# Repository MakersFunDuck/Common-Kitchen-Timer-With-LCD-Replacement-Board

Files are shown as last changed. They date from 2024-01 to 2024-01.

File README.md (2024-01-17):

# Common Kitchen Timer With an LCD-Replacement Board
A replacement PCB board for common 4 digit 7 segment LCD kitchen timers

It uses a cheap TM1621D LCD driver. You can solder either Attiny13A, or ESP12E module. 

The "Print" function can print out supported letters on the screen. However it is not optimised for memory constains for Attiny13A.

<p align="center">
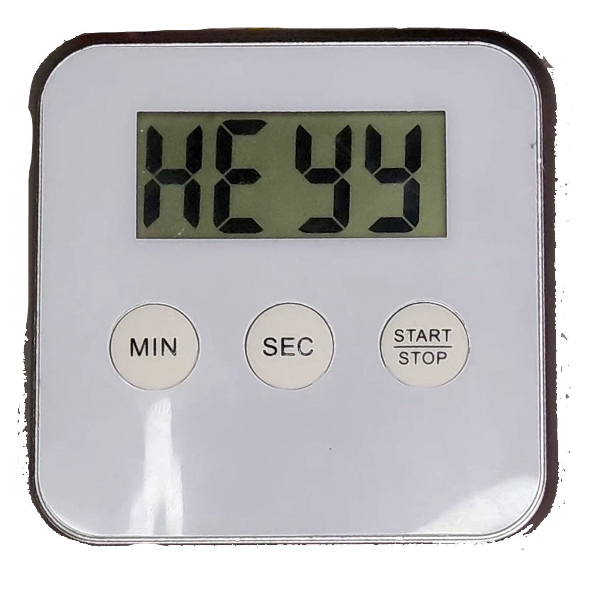
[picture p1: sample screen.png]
Sample Screen
  

</p>

**Folder descriptions:**

**Datasheets:** Where datasheets of the components are located (also translations from Chinese)

**Fabrication files:** Gerber files. You can just upload those to any PCB manufacturer website to get your PCB.

**Firmware:** Code examples which is written using Arduino framework.

**KiCAD files:** KiCAD schematics and PCB files

**Schematics and Layout files:** PDF files for the PCB and Schematics.

If you want to use another LCD, or make your own PCB designs, I explained them in a video if you are interested. 
https://youtu.be/JNZbfLtlbZA

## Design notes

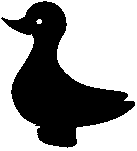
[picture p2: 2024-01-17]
KiCAD files/duck symb.bmp

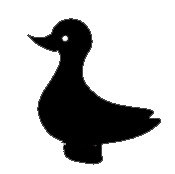
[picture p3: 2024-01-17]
KiCAD files/Screenshot 2023-12-29 142127.png

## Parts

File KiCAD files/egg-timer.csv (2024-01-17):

# | Reference | Qty | Value | Footprint | DNP
1 | BZ1 | 1 | Buzzer | Buzzer_Beeper:Buzzer_12x9.5RM7.6
2 | C1, C3 | 2 | 10uF | Capacitor_SMD:C_0805_2012Metric_Pad1.18x1.45mm_HandSolder
3 | C2, C4 | 2 | 100nF | Capacitor_SMD:C_0805_2012Metric_Pad1.18x1.45mm_HandSolder
4 | J1 | 1 | Conn_01x05 | Connector_PinHeader_2.00mm:PinHeader_1x05_P2.00mm_Vertical
5 | J2, J3, J4, J5 | 4 | Conn_01x01 | Connector_PinHeader_2.00mm:PinHeader_1x01_P2.00mm_Vertical
6 | R1, R2, R4 | 3 | 1k | Resistor_SMD:R_0805_2012Metric_Pad1.20x1.40mm_HandSolder
7 | R3 | 1 | 1K | Resistor_SMD:R_0805_2012Metric_Pad1.20x1.40mm_HandSolder
8 | R5 | 1 | 0Ω | Resistor_SMD:R_0805_2012Metric_Pad1.20x1.40mm_HandSolder
9 | RV1 | 1 | Varistor | Potentiometer_THT:Potentiometer_Runtron_RM-065_Vertical
10 | SW1, SW2, SW3 | 3 | SW_Push | lcd:contact pad
11 | U1 | 1 | ESP-12E | RF_Module:ESP-12E
12 | U2 | 1 | TM1621D | Package_SO:SOIC-24W_7.5x15.4mm_P1.27mm
13 | U3 | 1 | bare-lcd | lcd:bare-lcd-footprint12
14 | U4 | 1 | AMS1117-3.3 | Package_TO_SOT_SMD:SOT-223-3_TabPin2
15 | U5 | 1 | ATtiny13A-S | Package_SO:SOIC-8W_5.3x5.3mm_P1.27mm

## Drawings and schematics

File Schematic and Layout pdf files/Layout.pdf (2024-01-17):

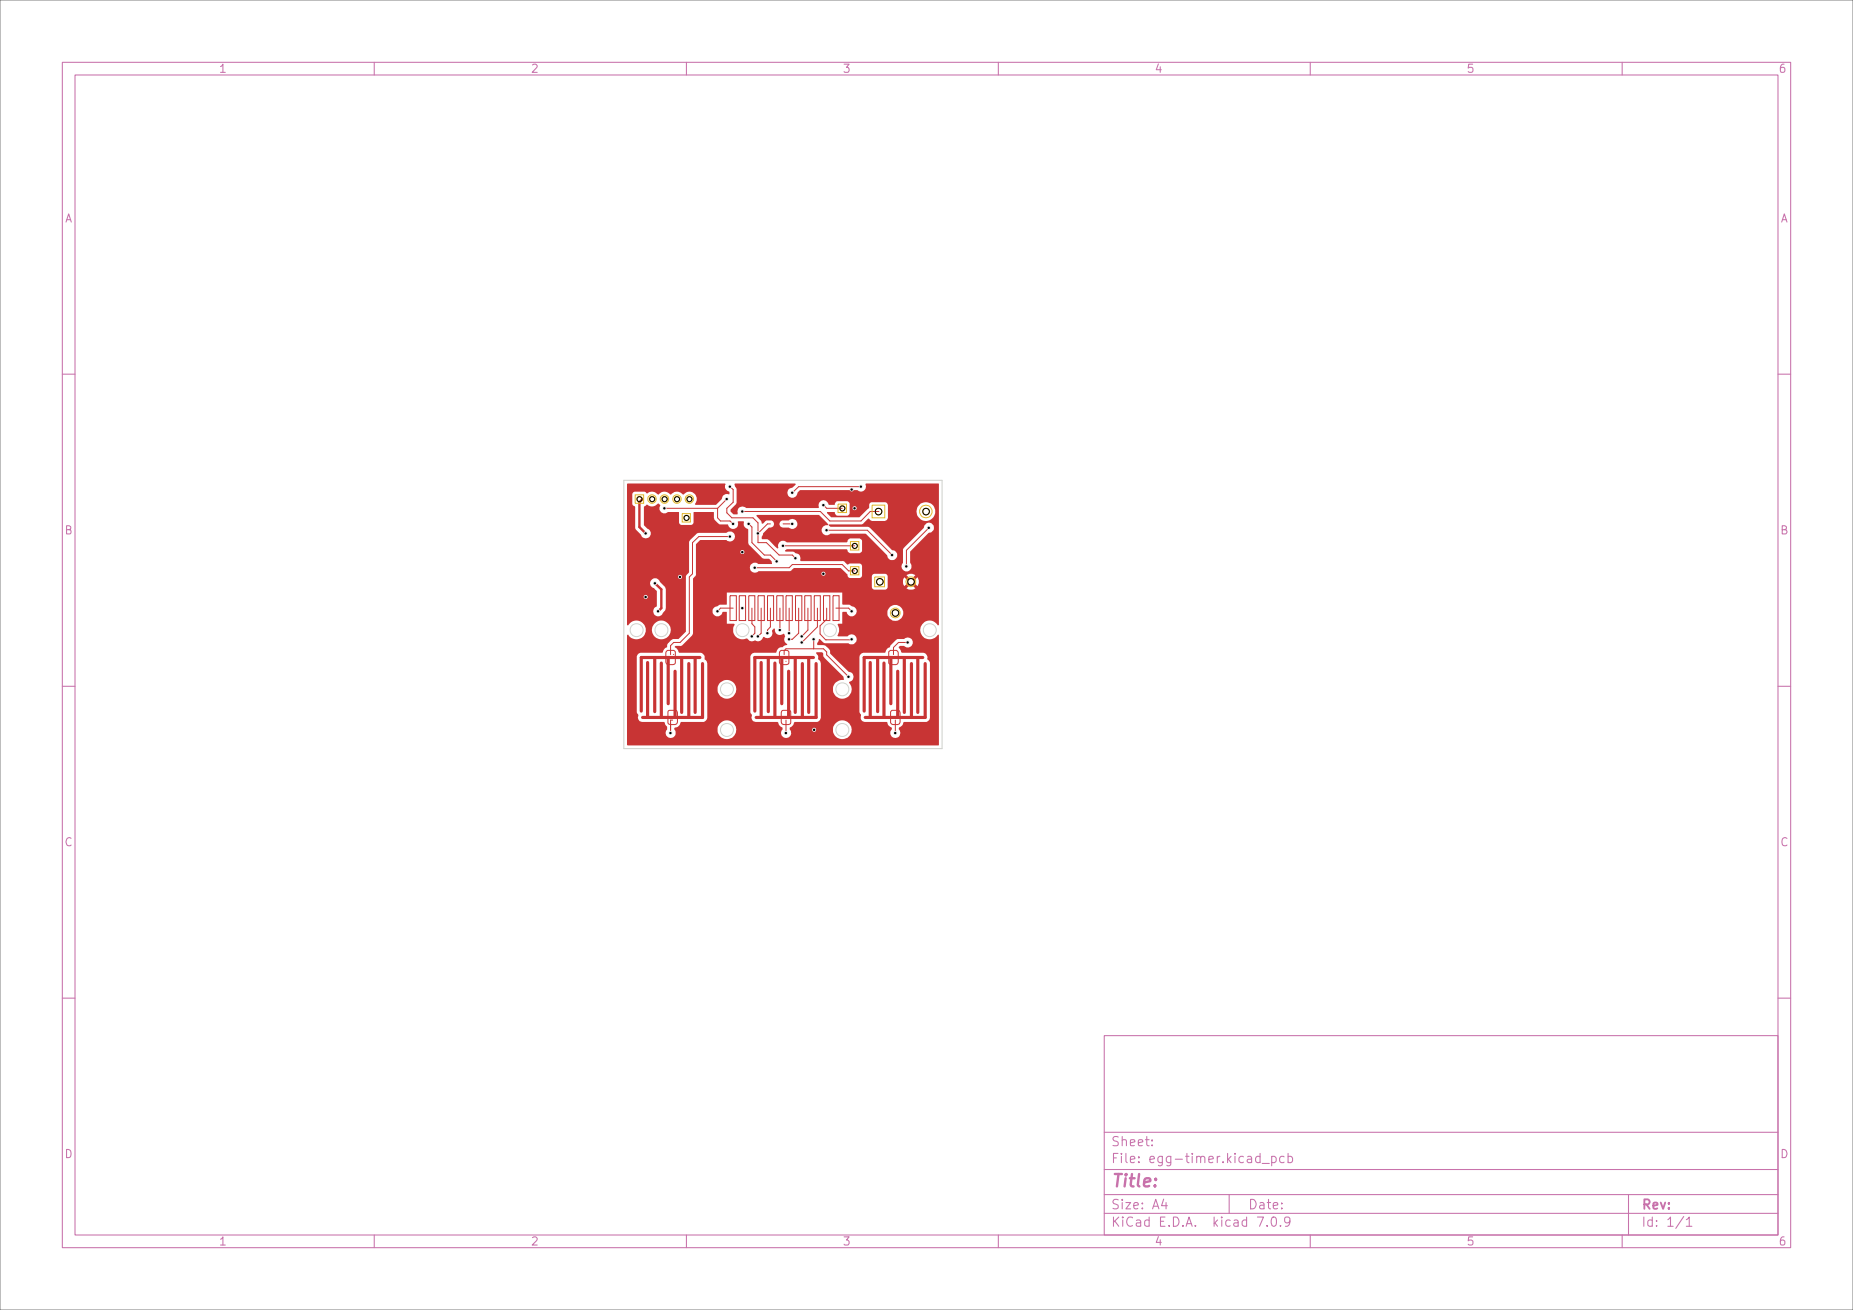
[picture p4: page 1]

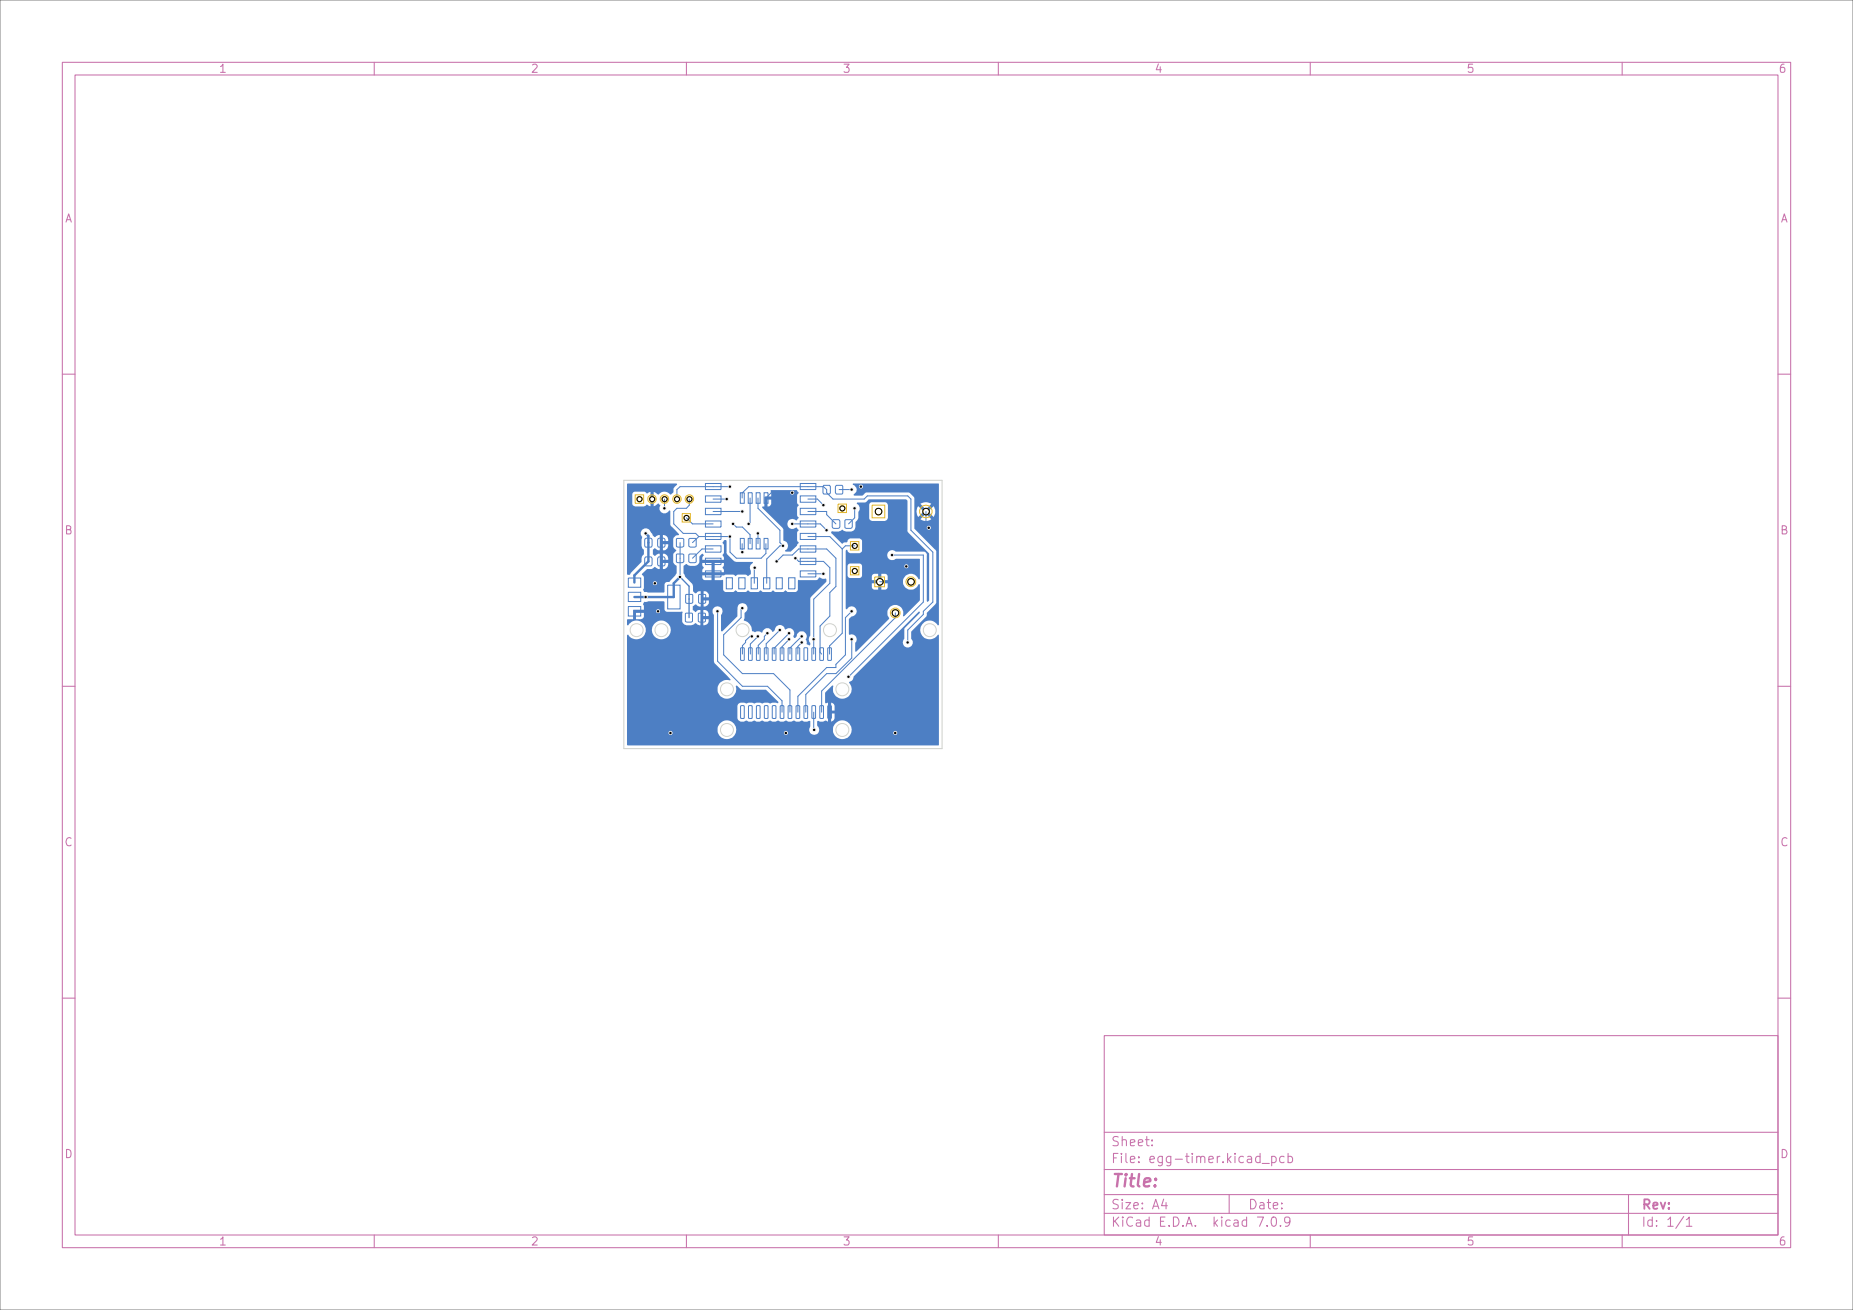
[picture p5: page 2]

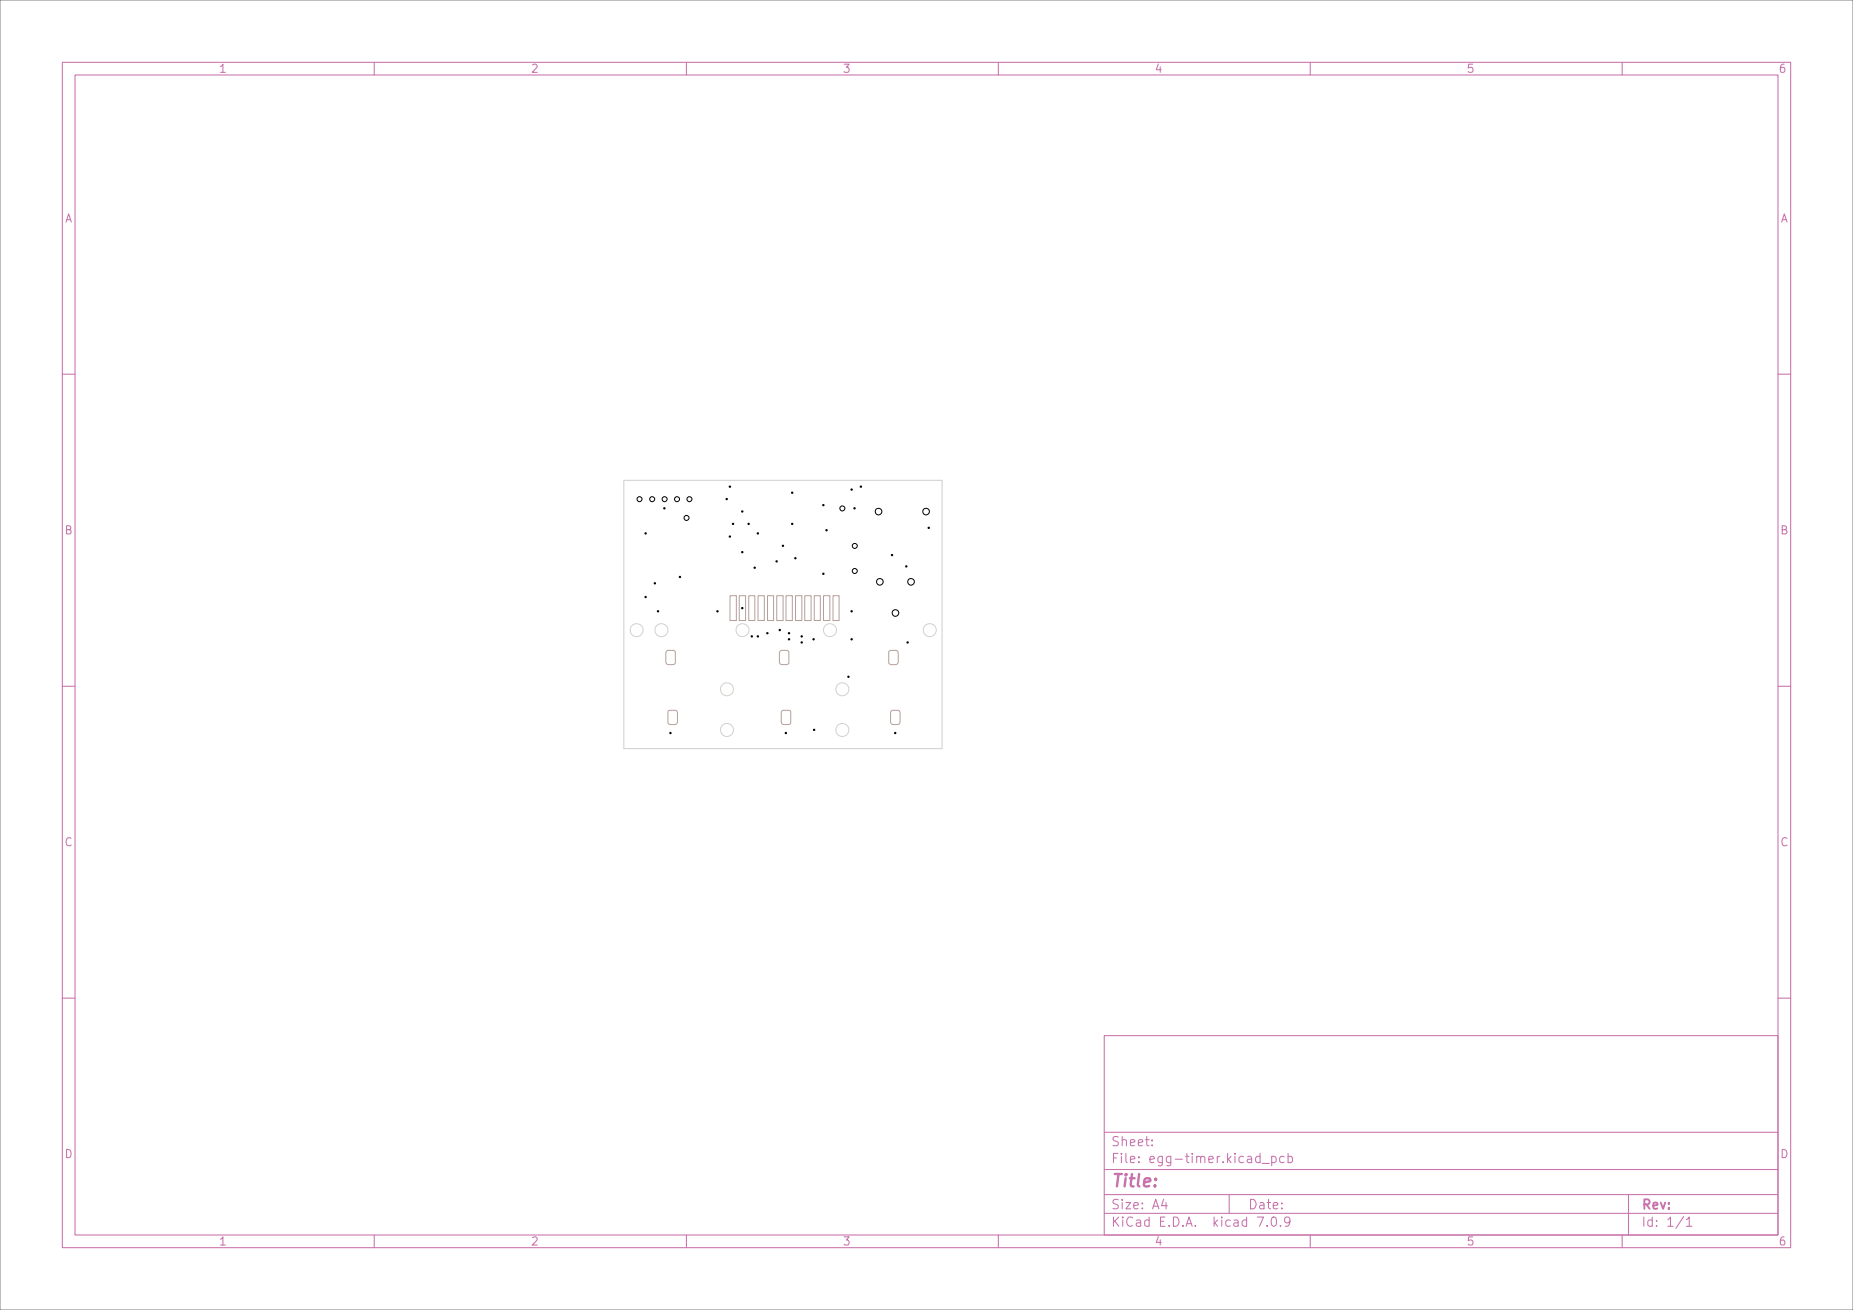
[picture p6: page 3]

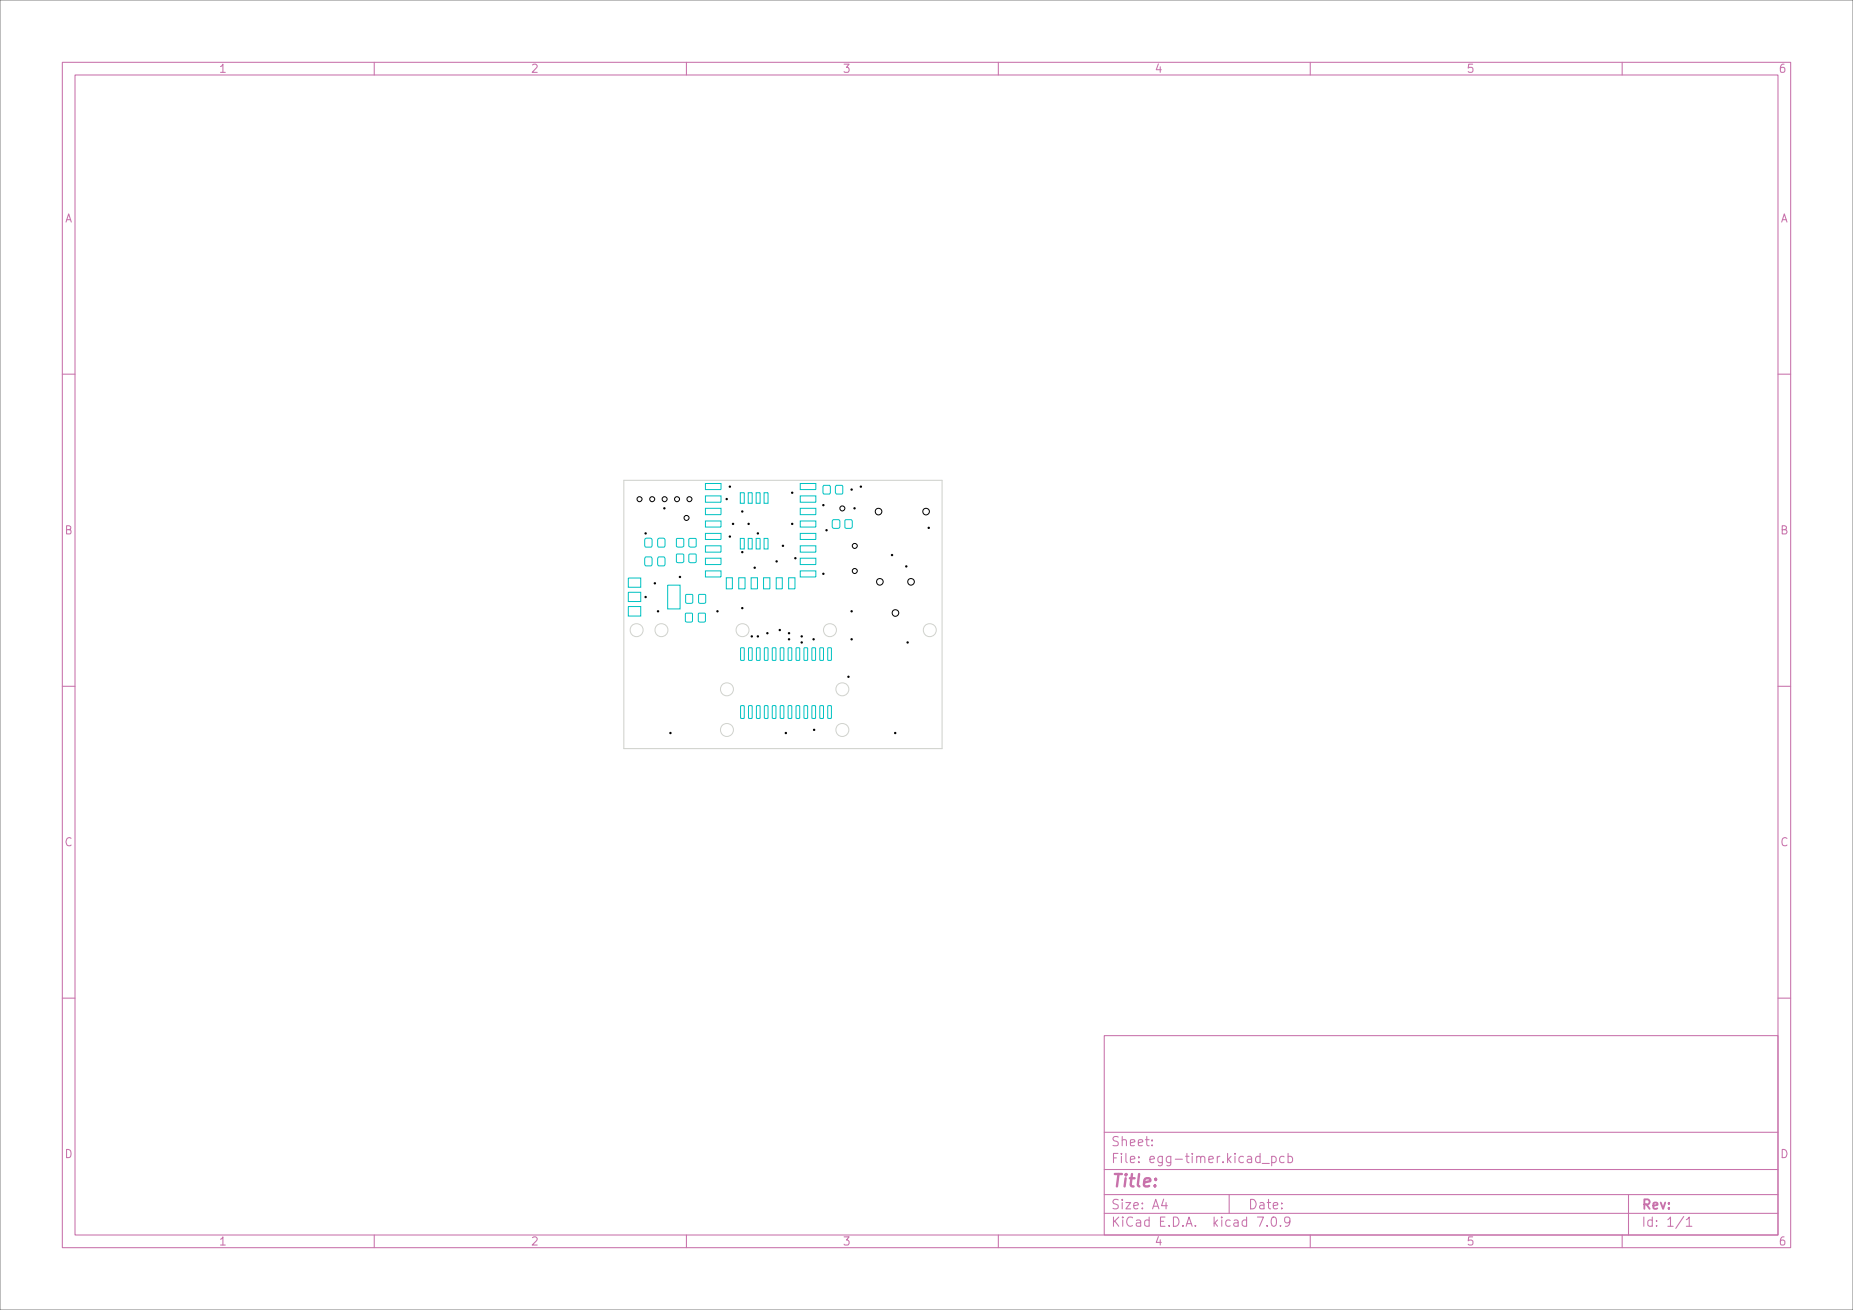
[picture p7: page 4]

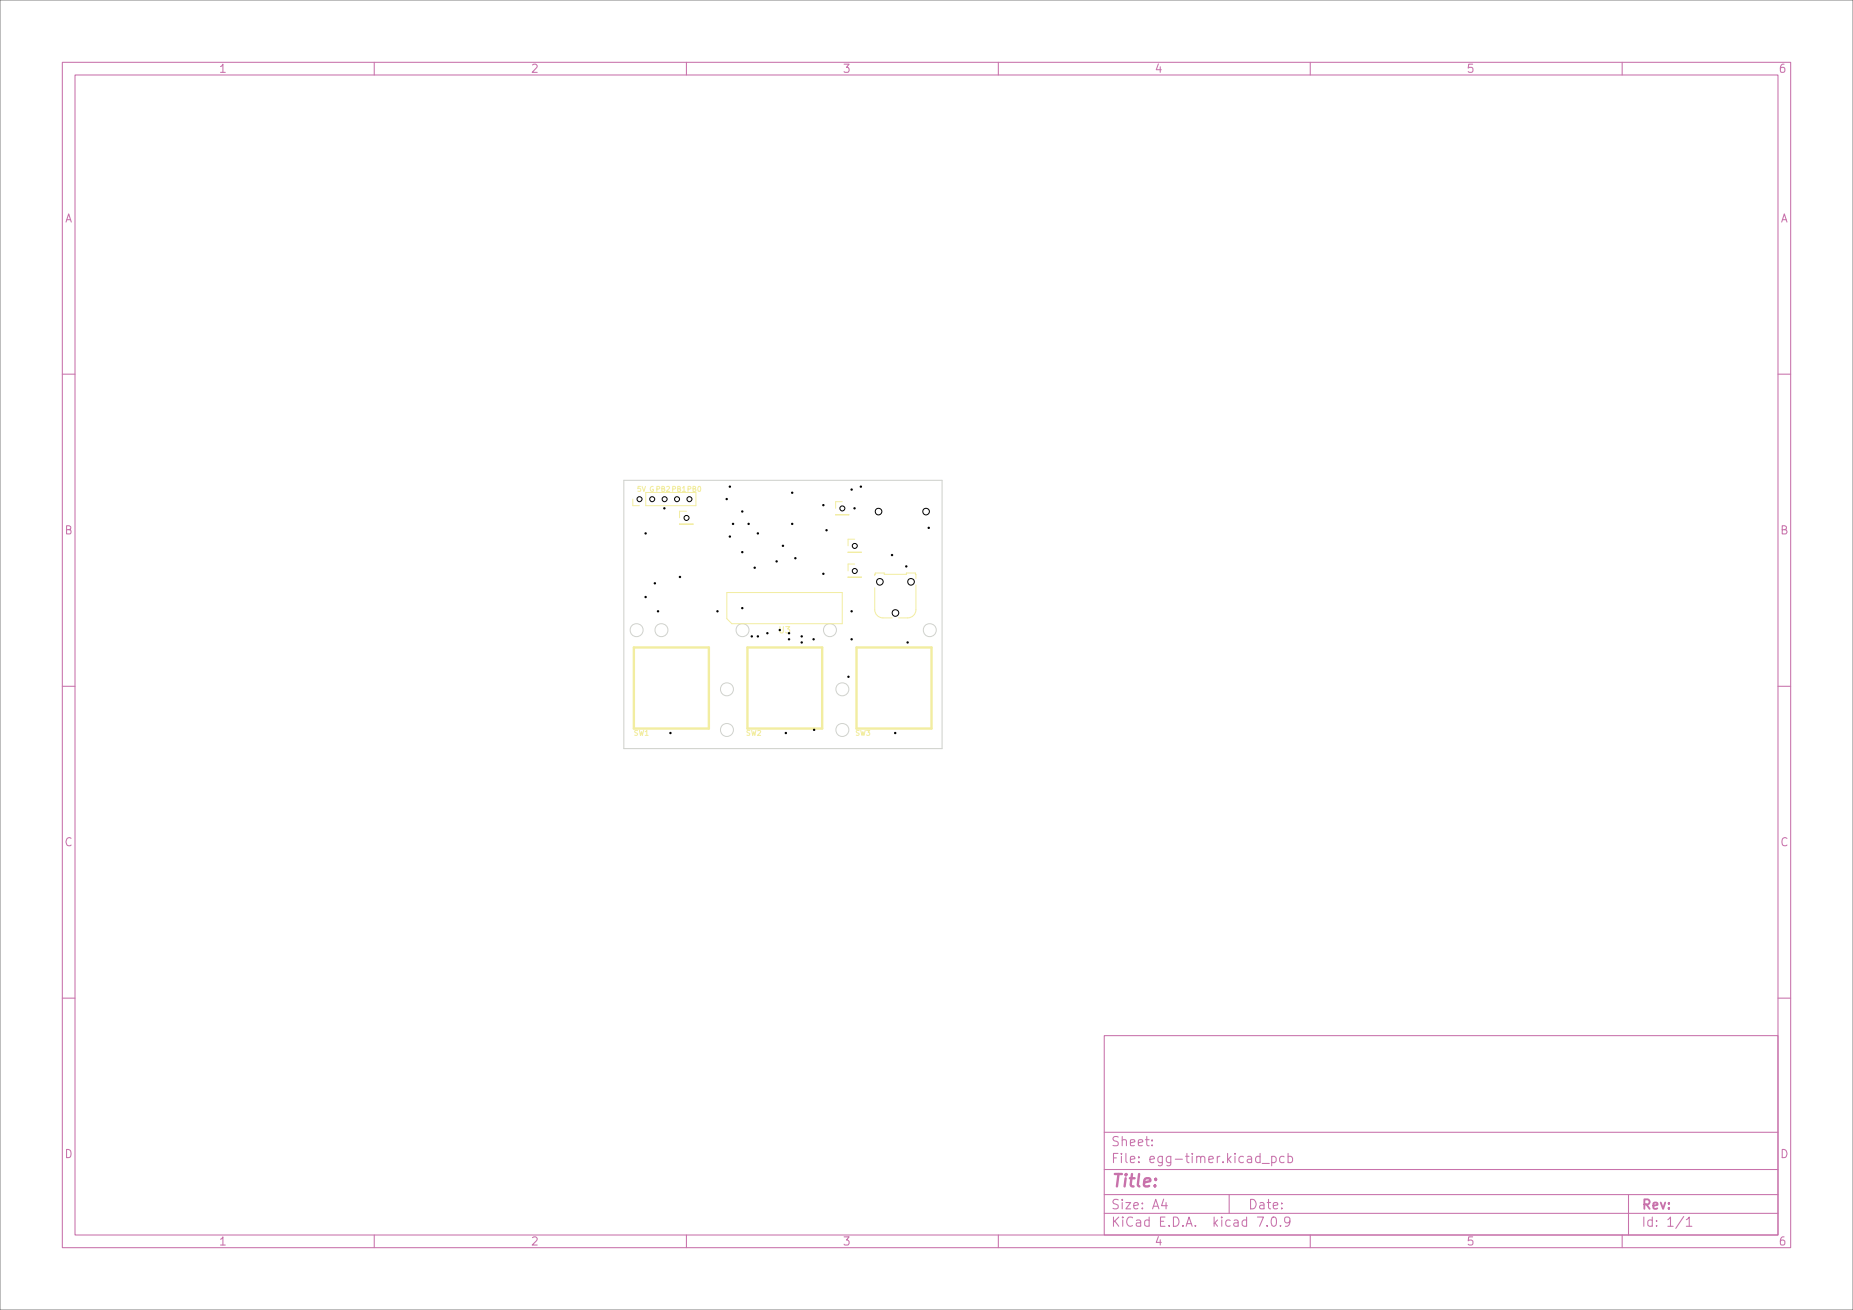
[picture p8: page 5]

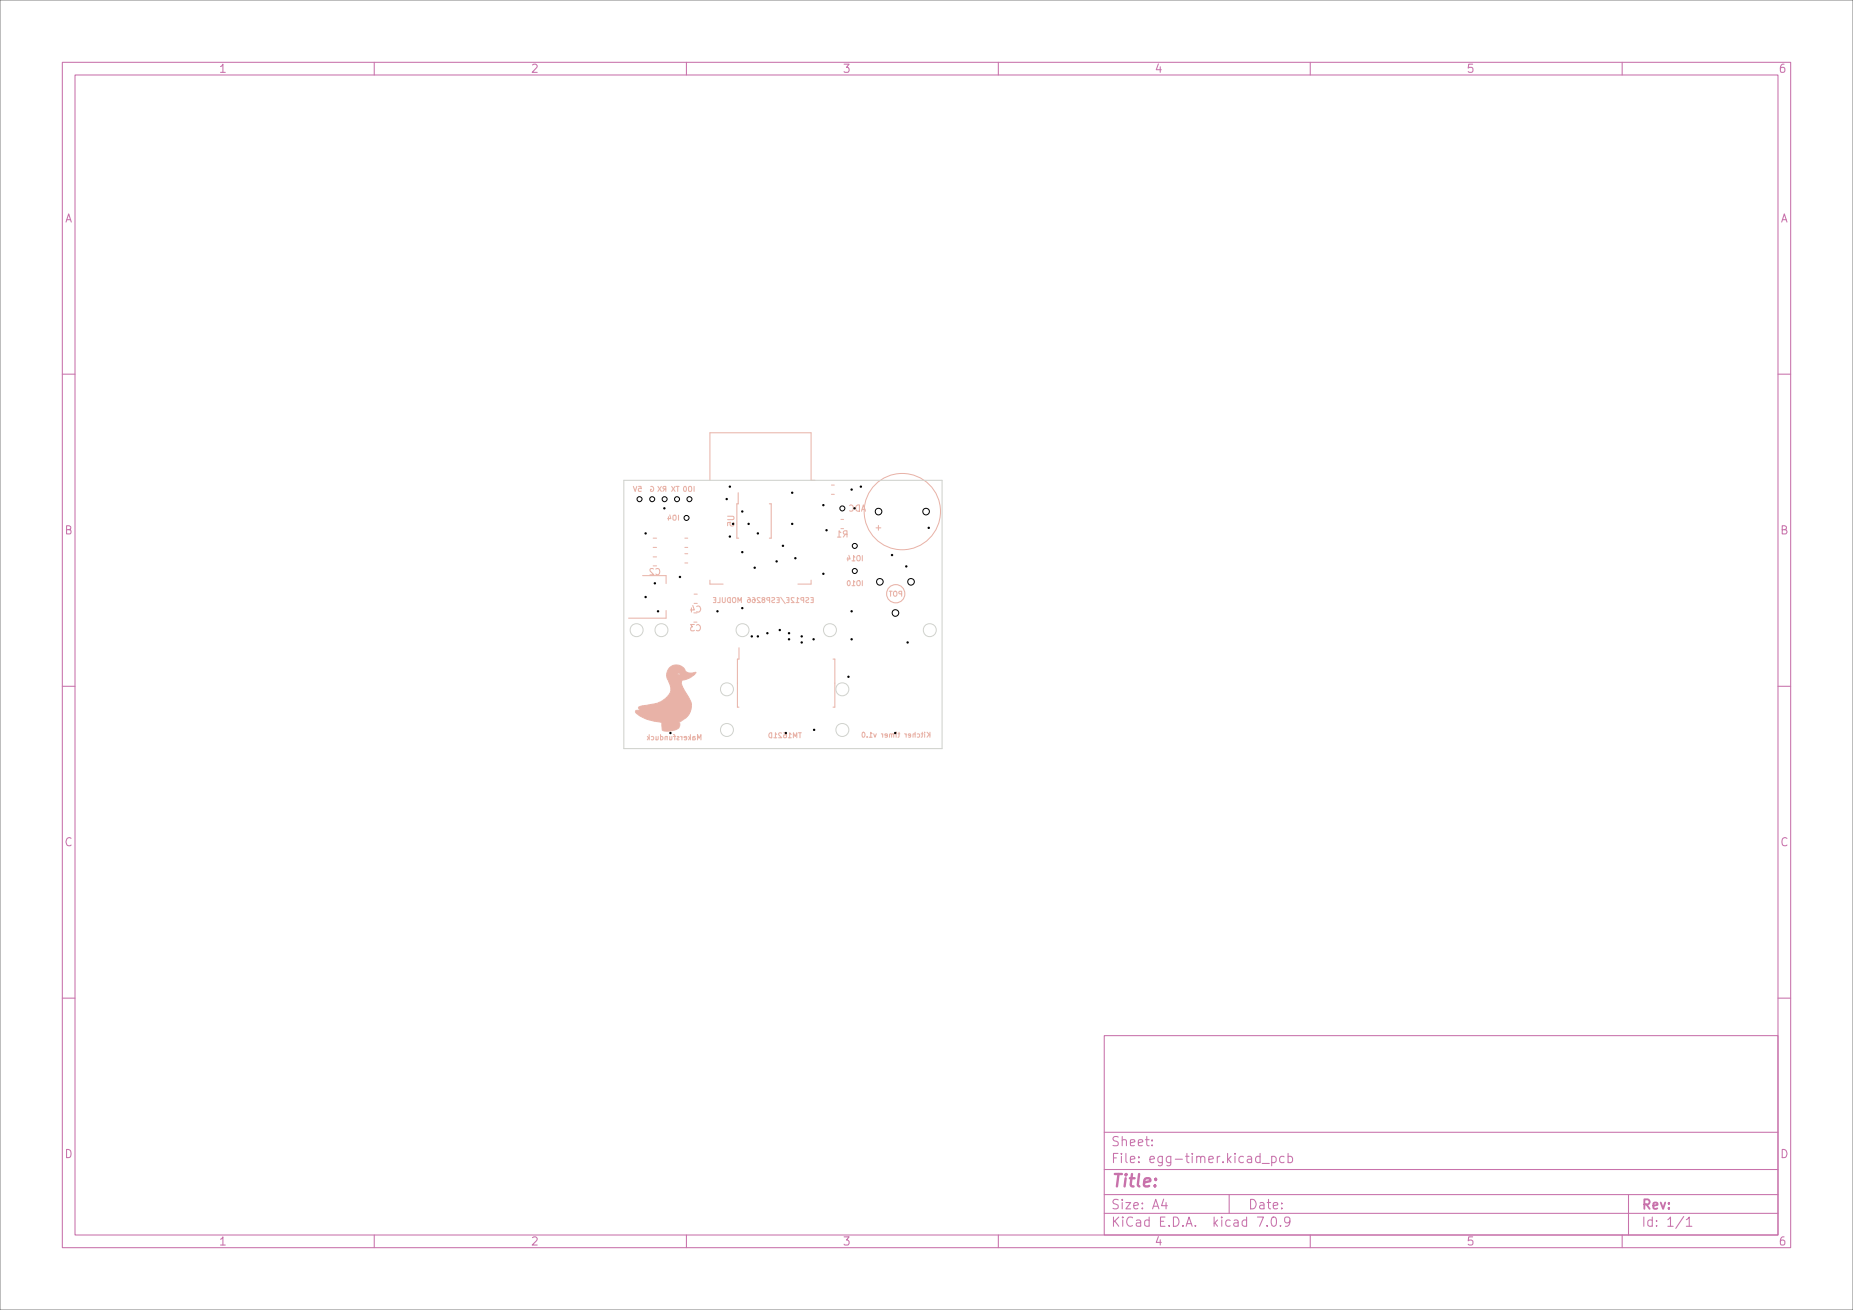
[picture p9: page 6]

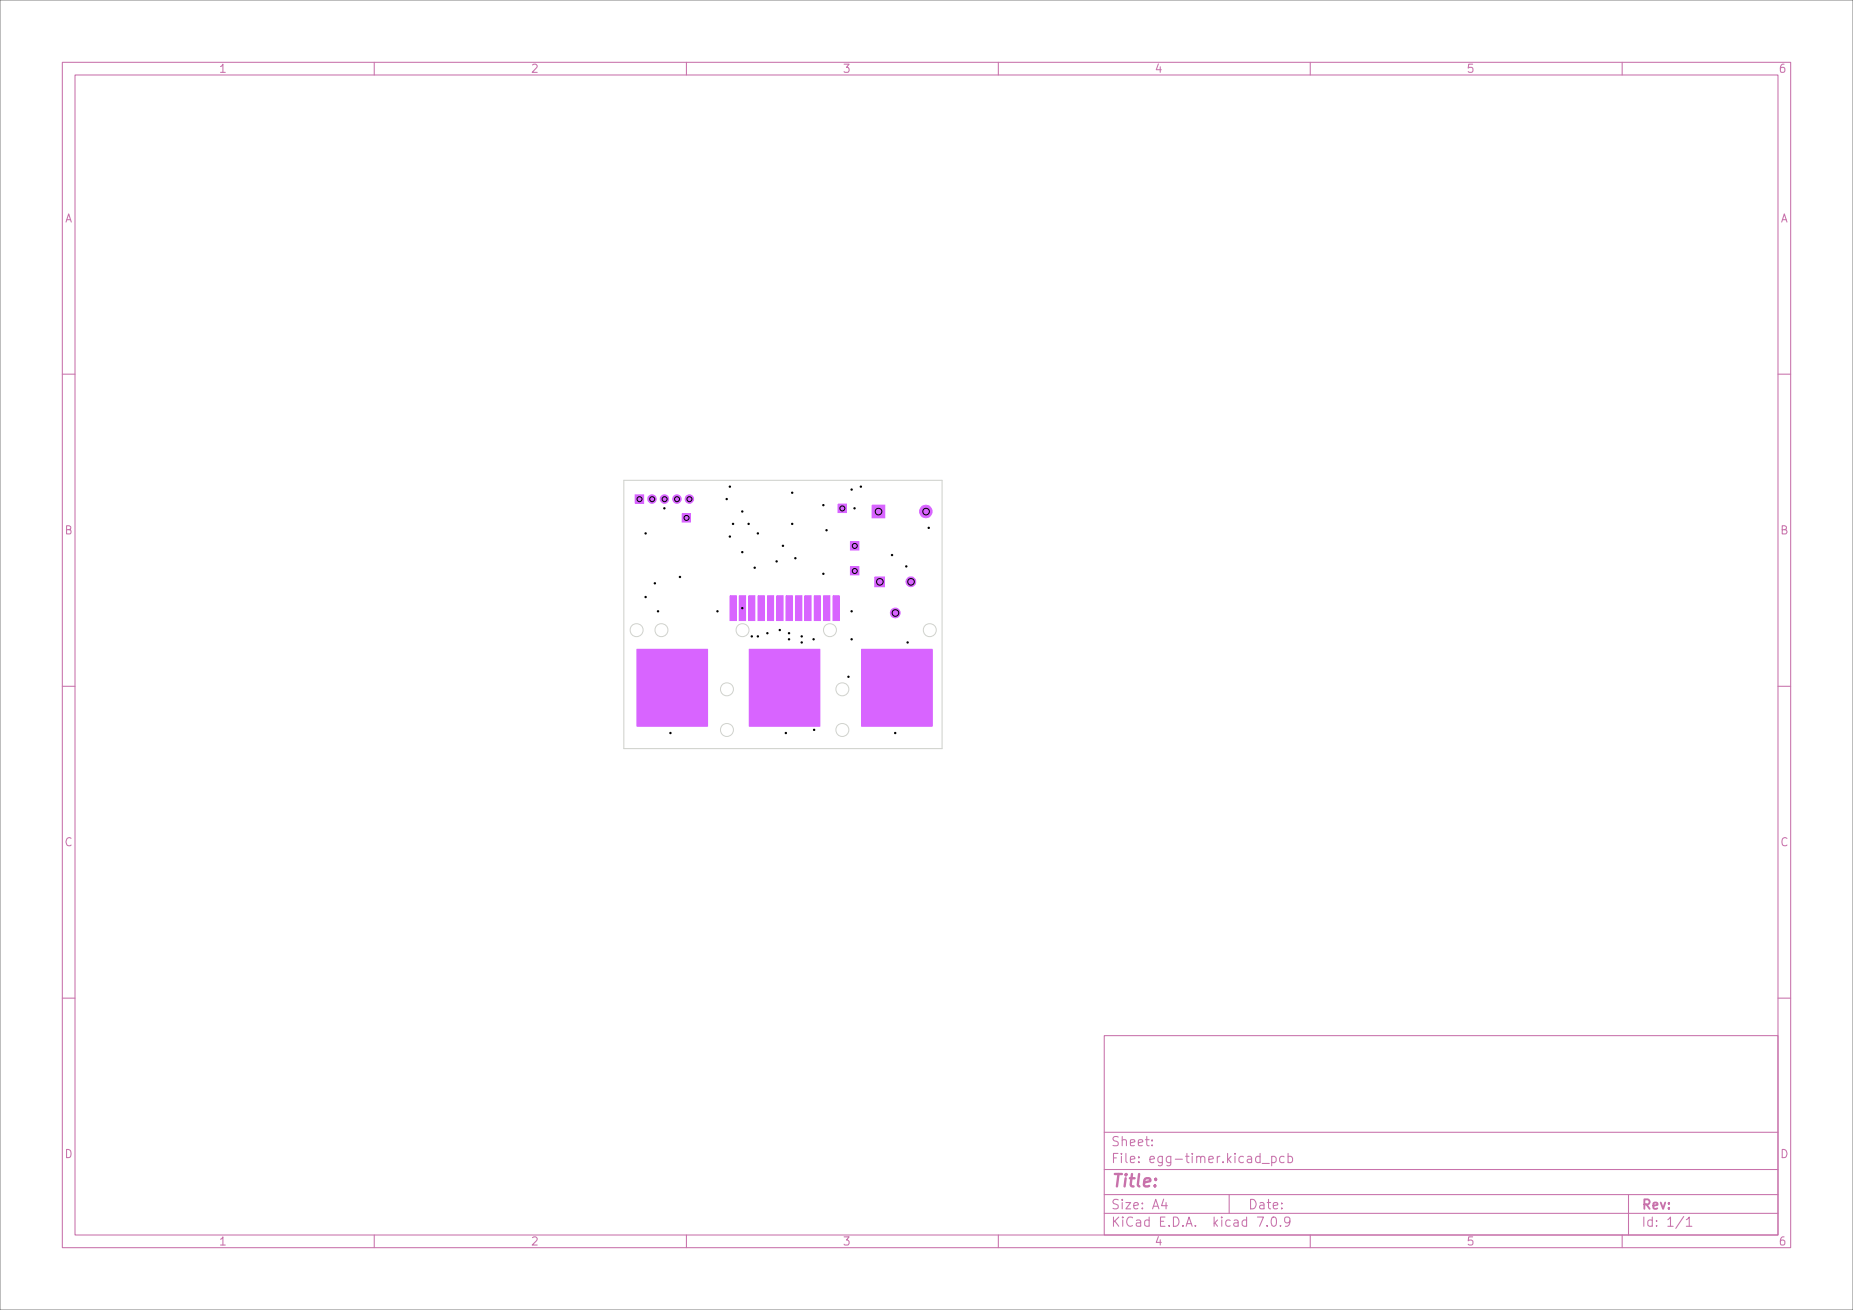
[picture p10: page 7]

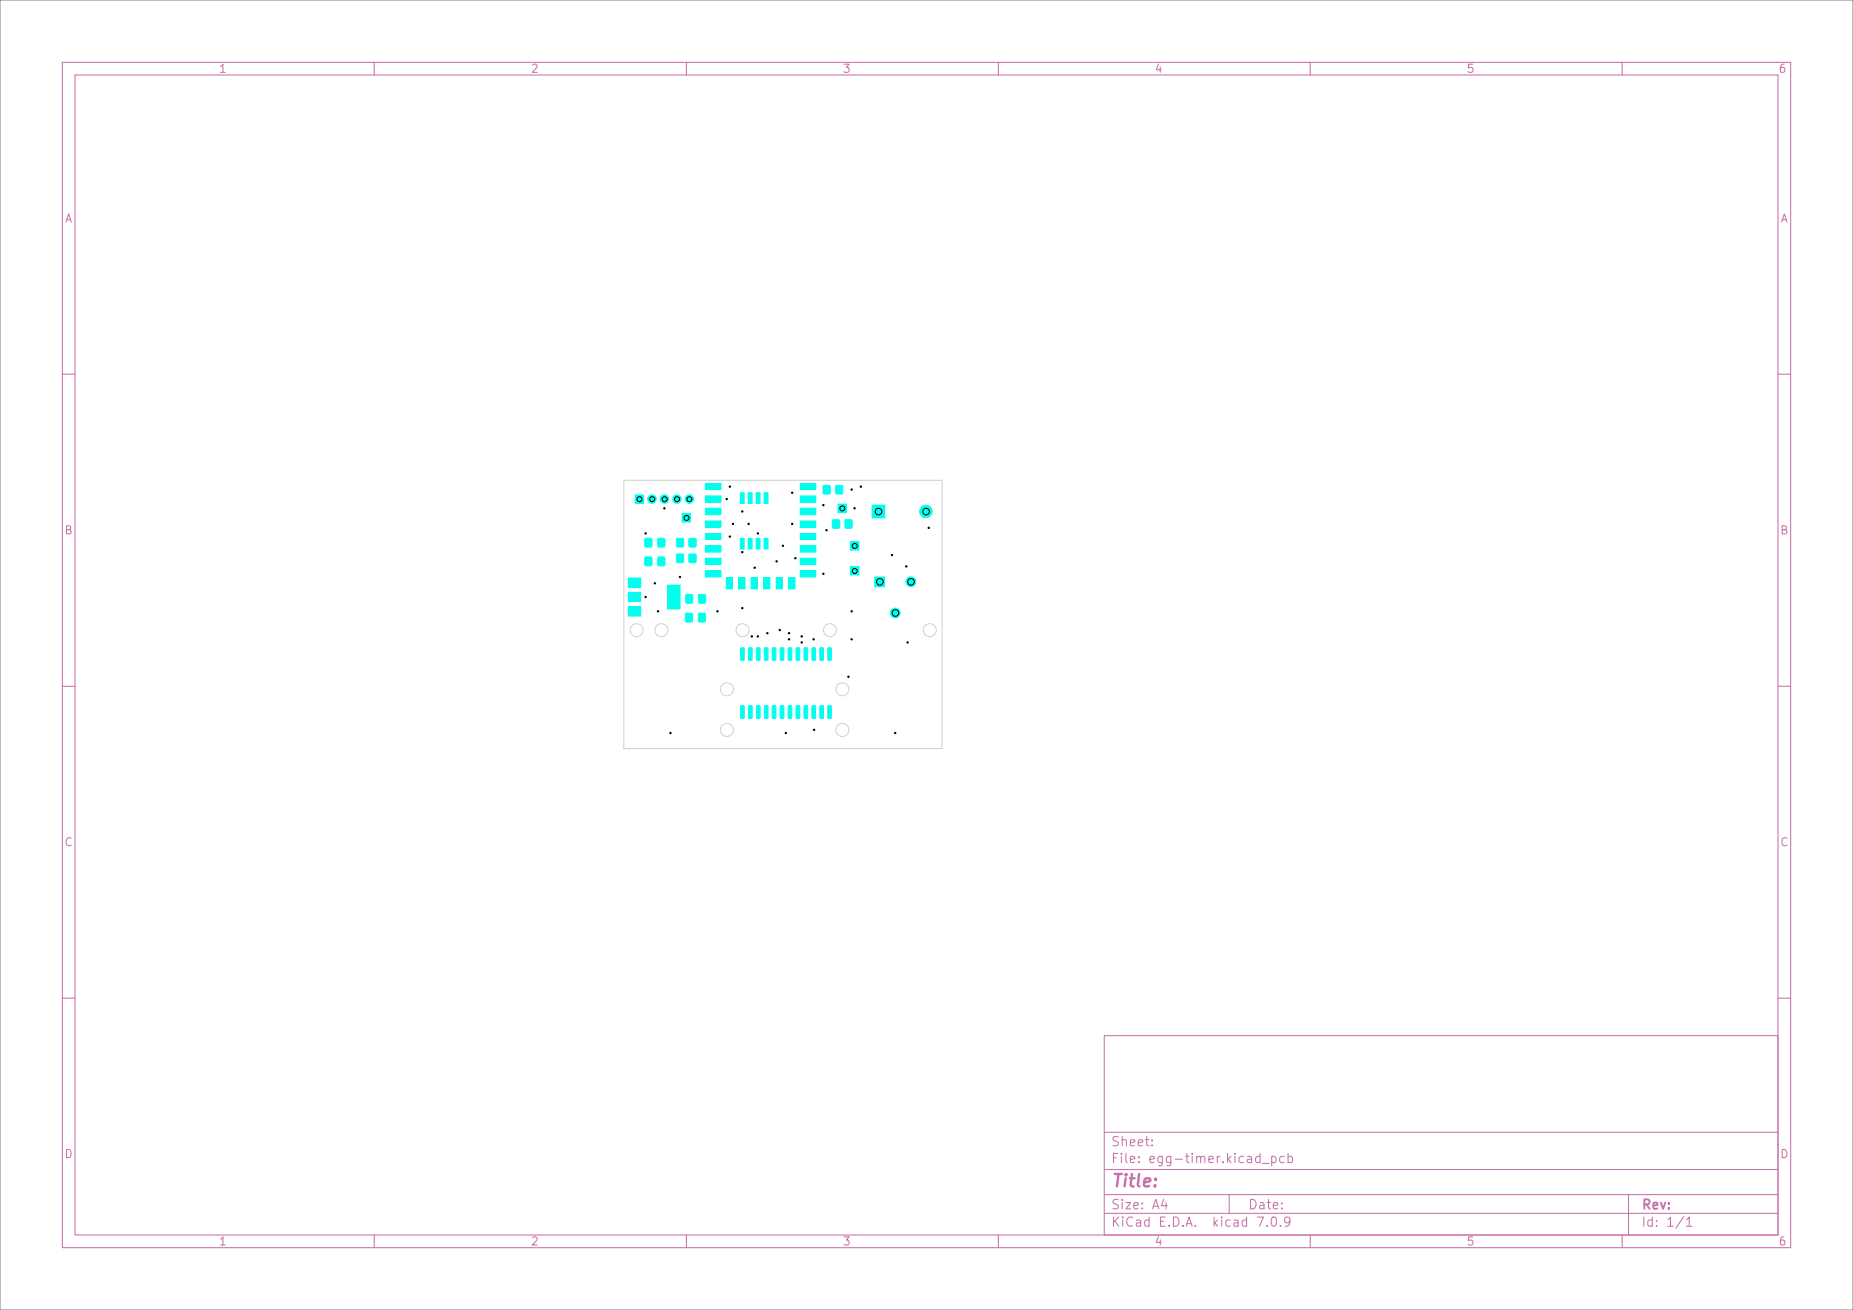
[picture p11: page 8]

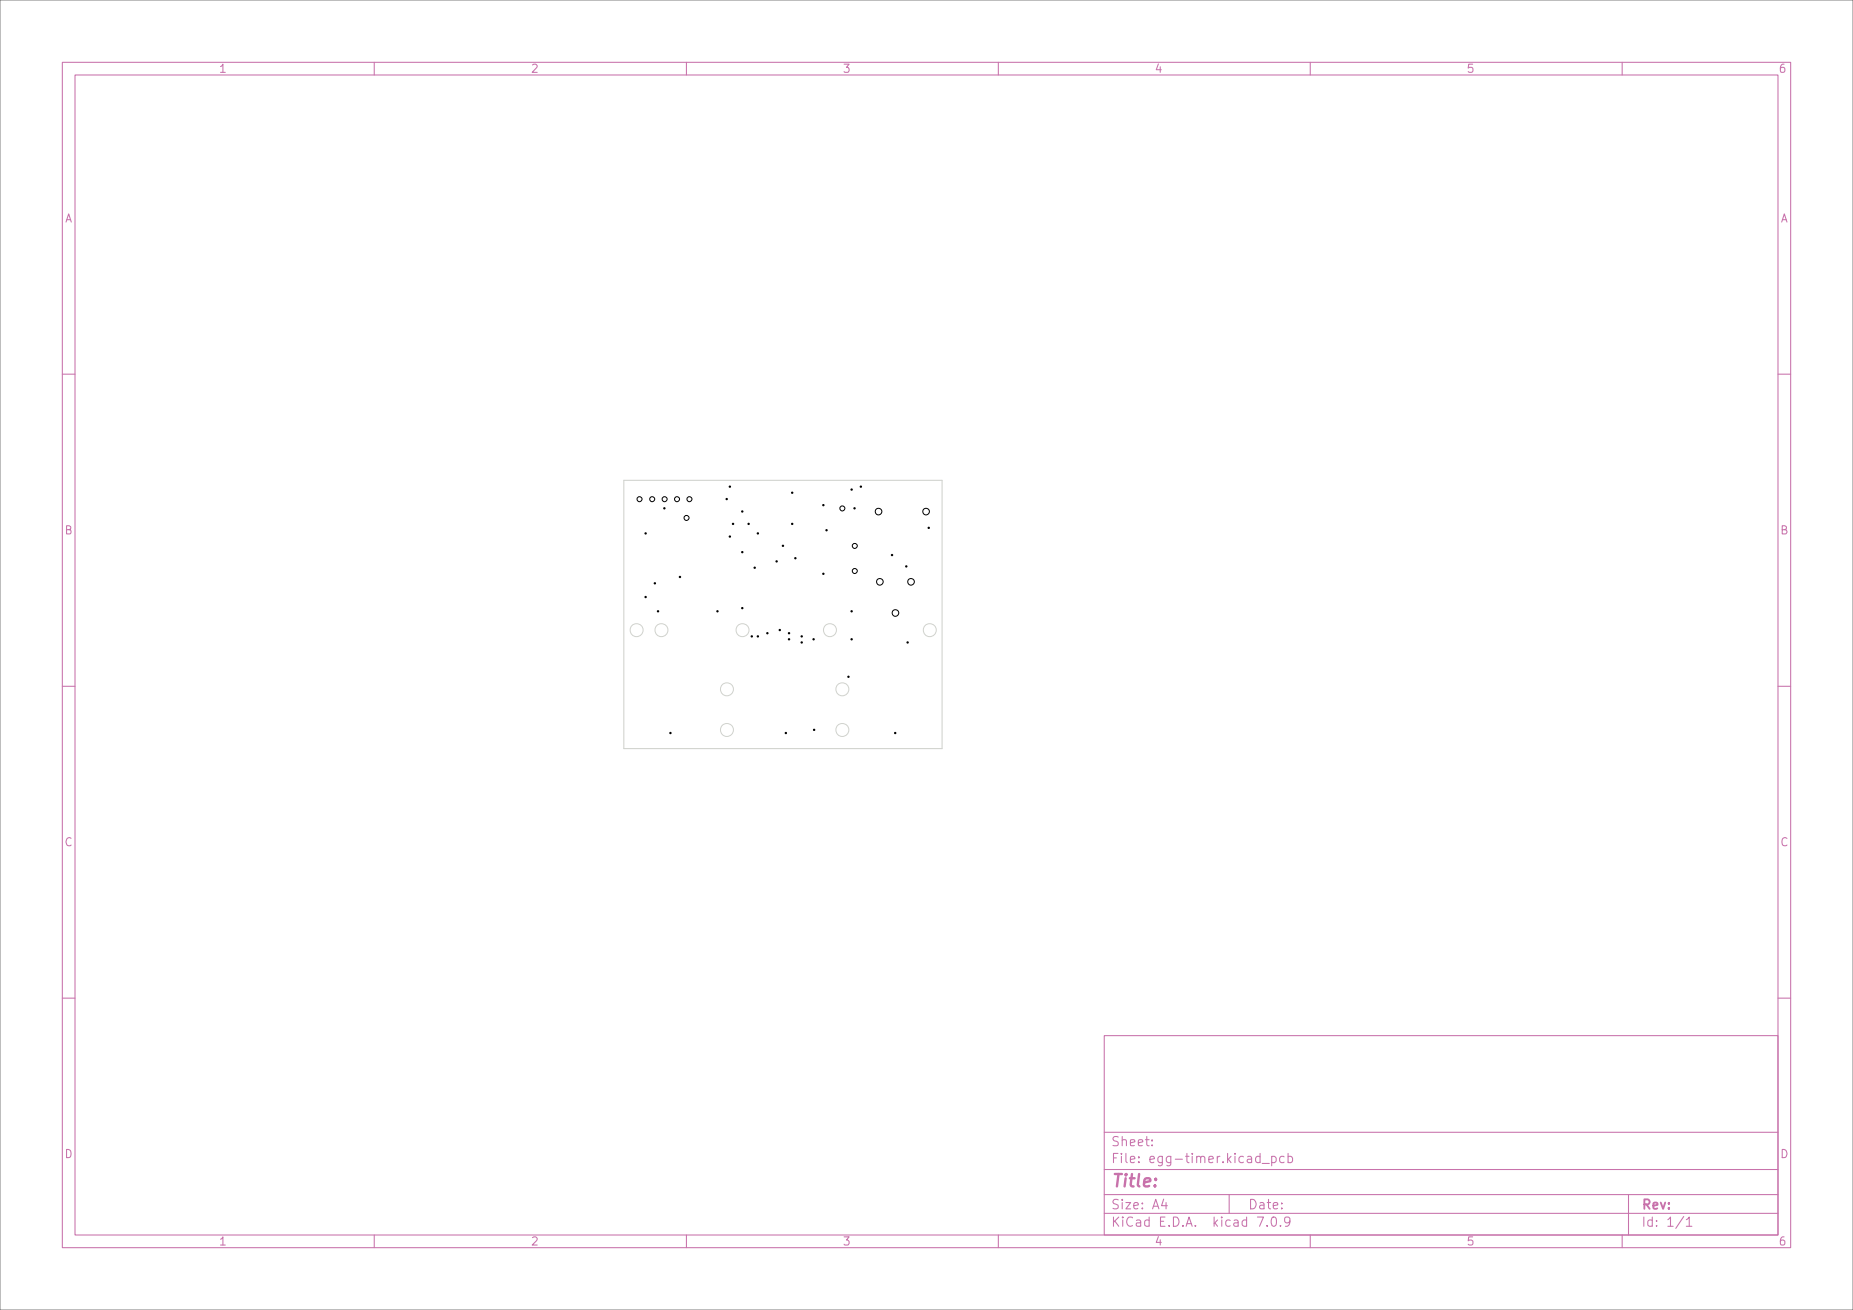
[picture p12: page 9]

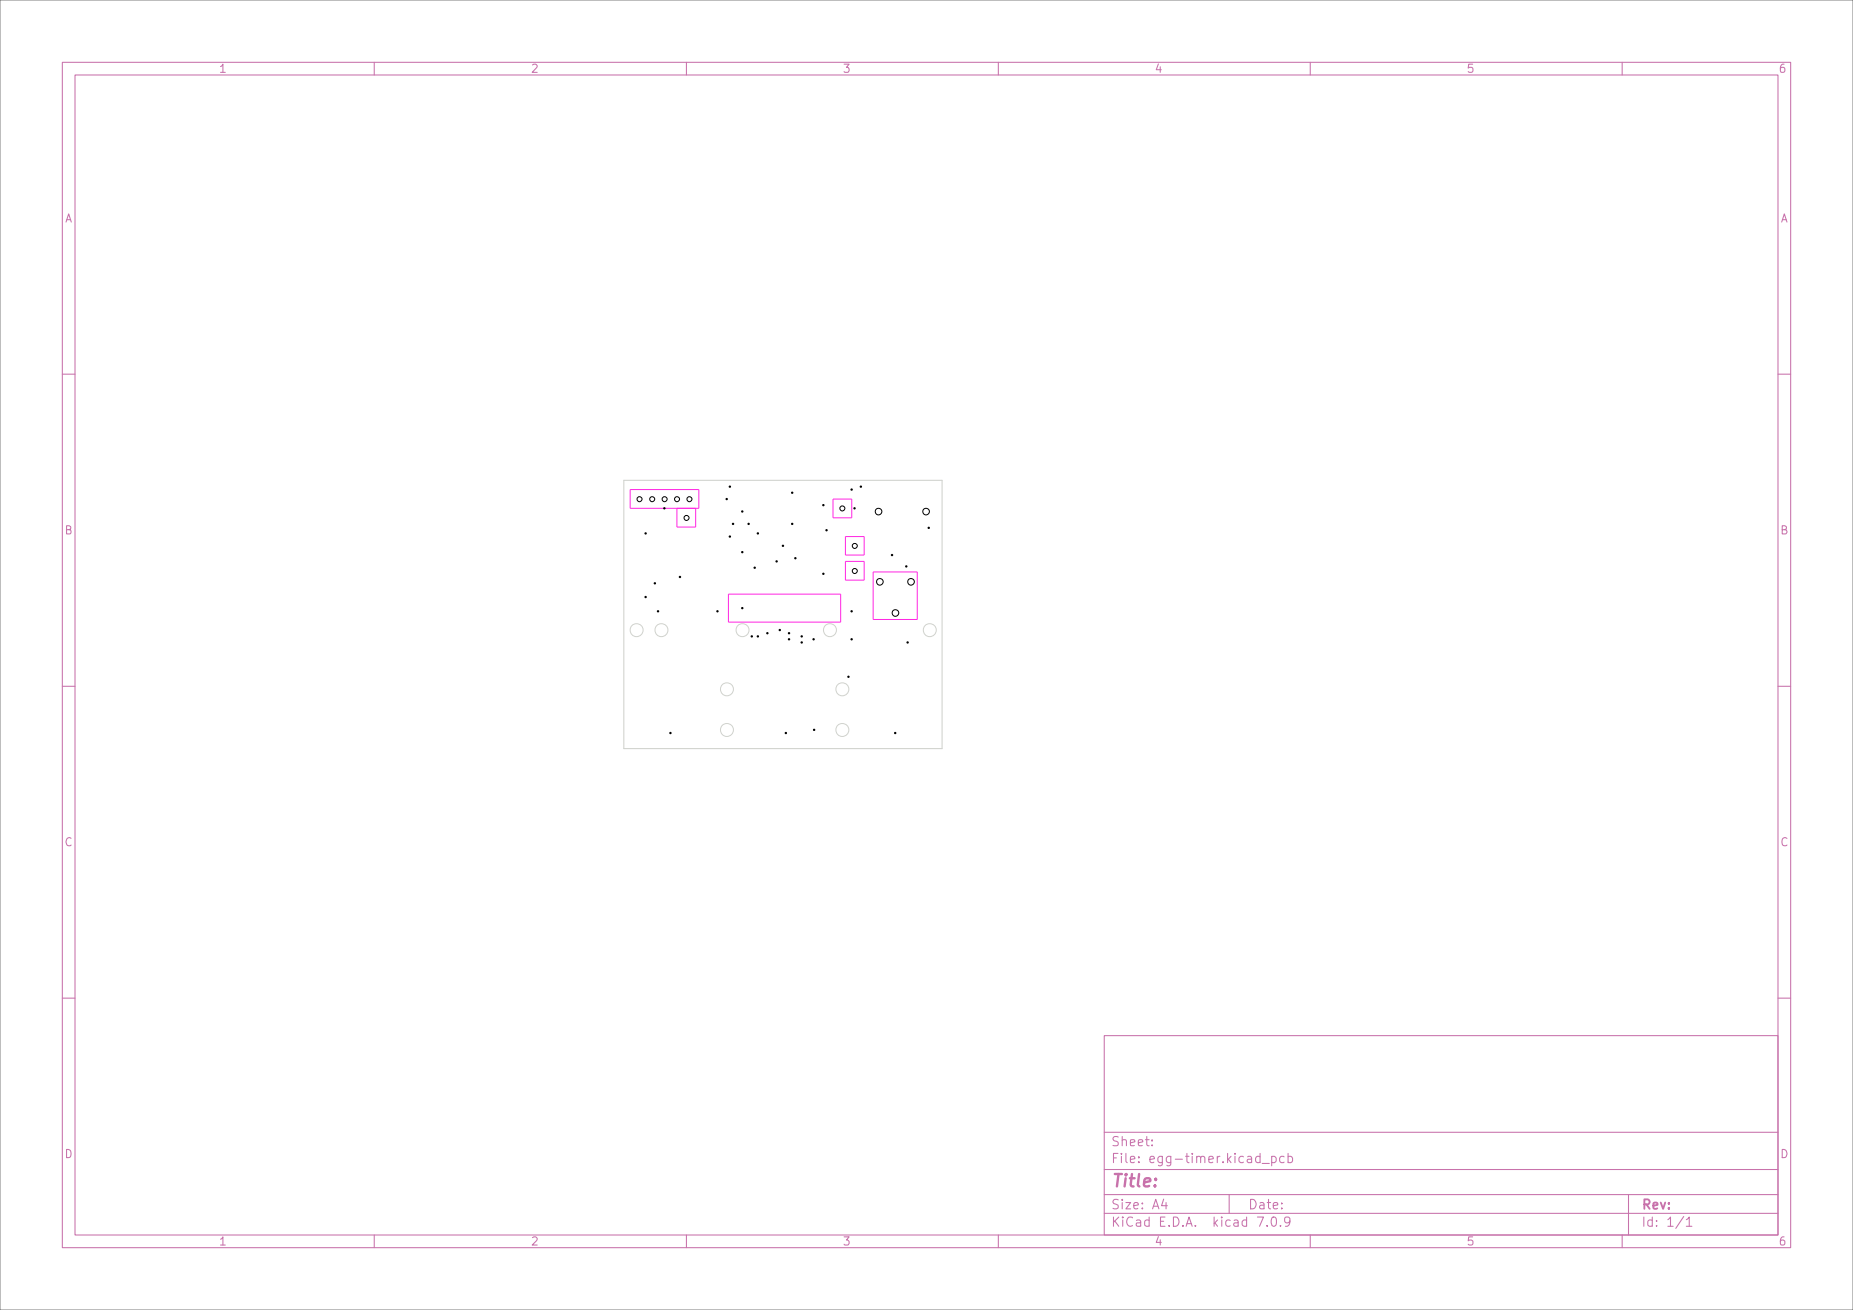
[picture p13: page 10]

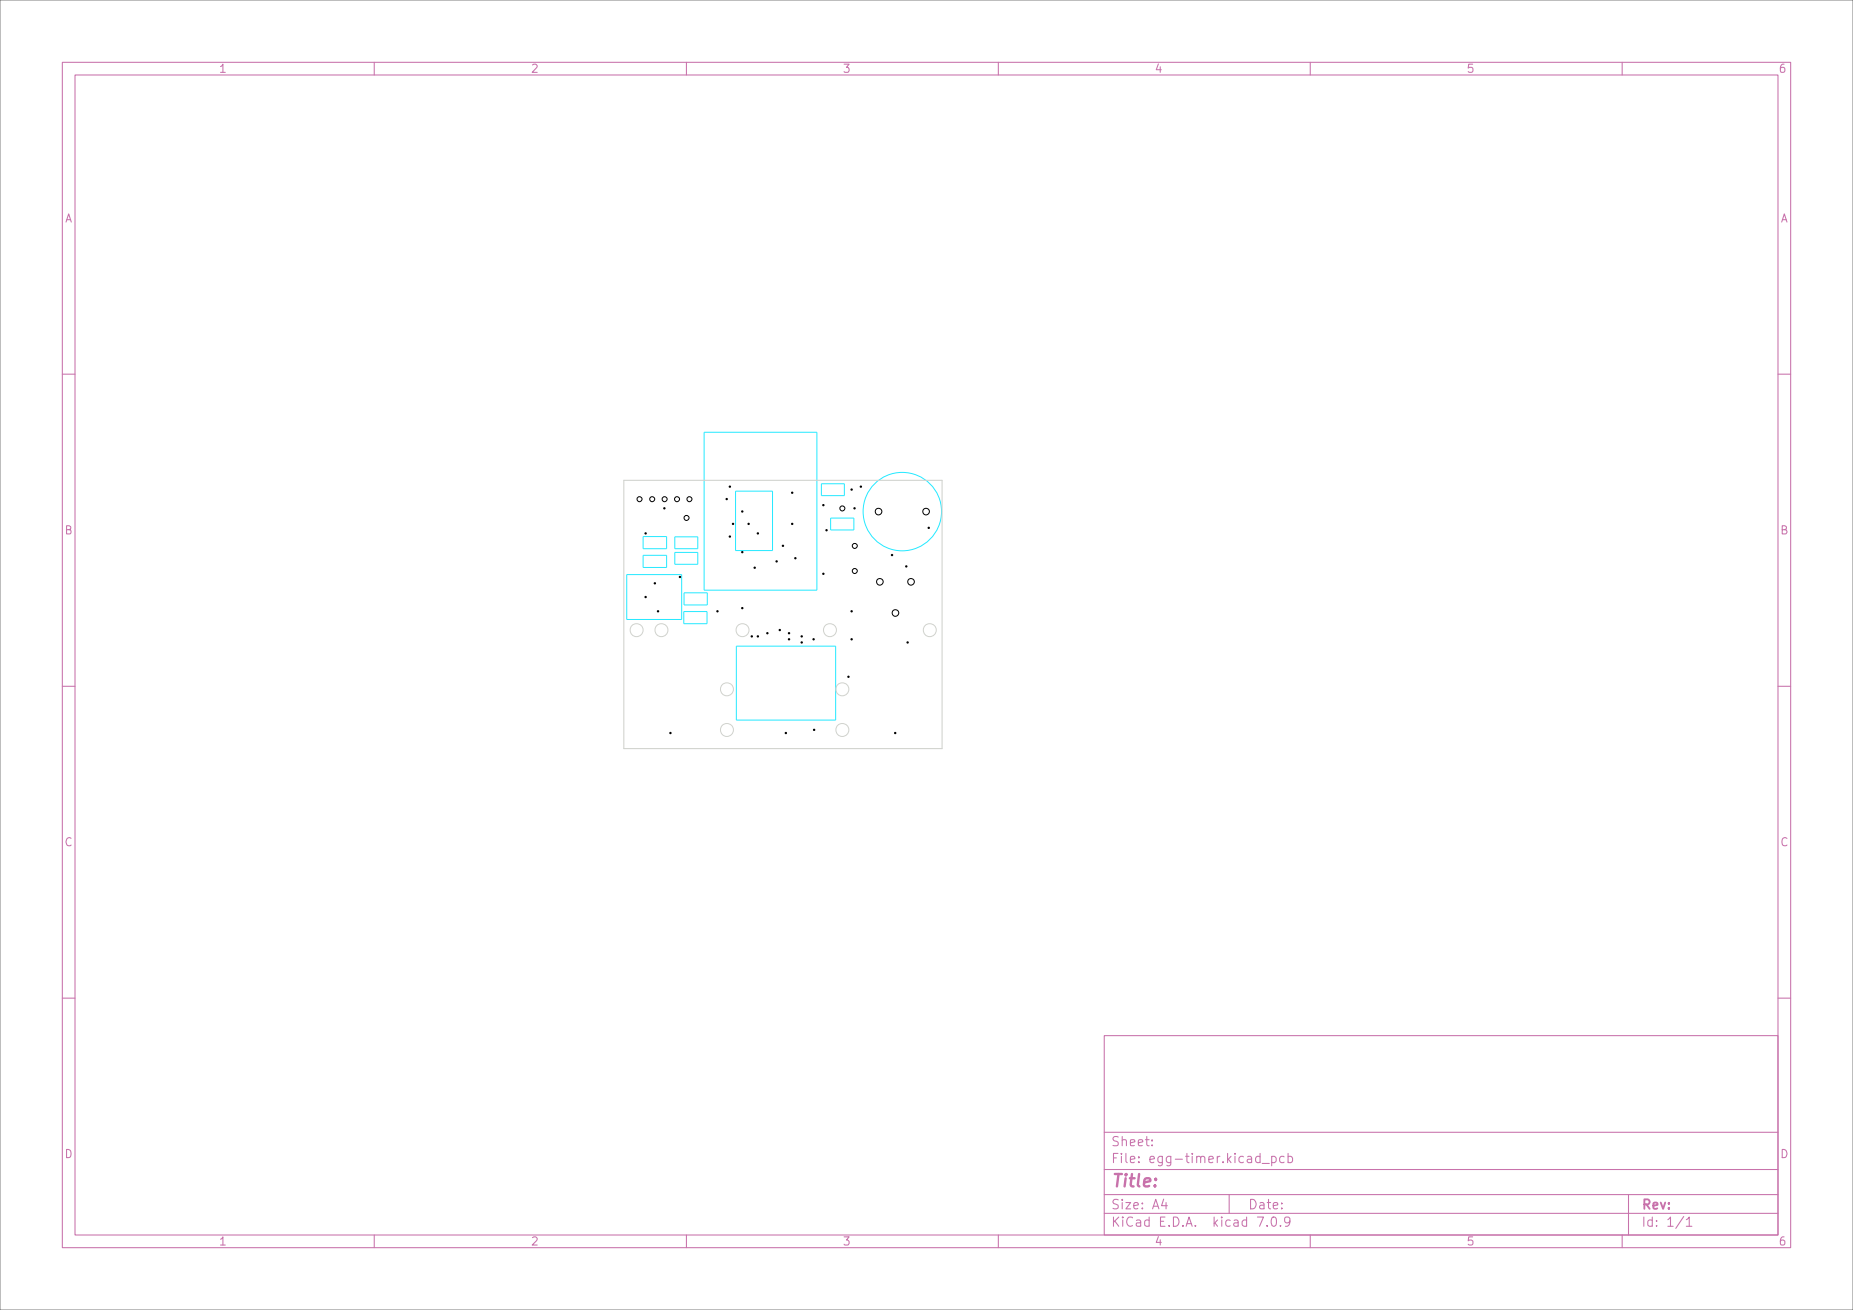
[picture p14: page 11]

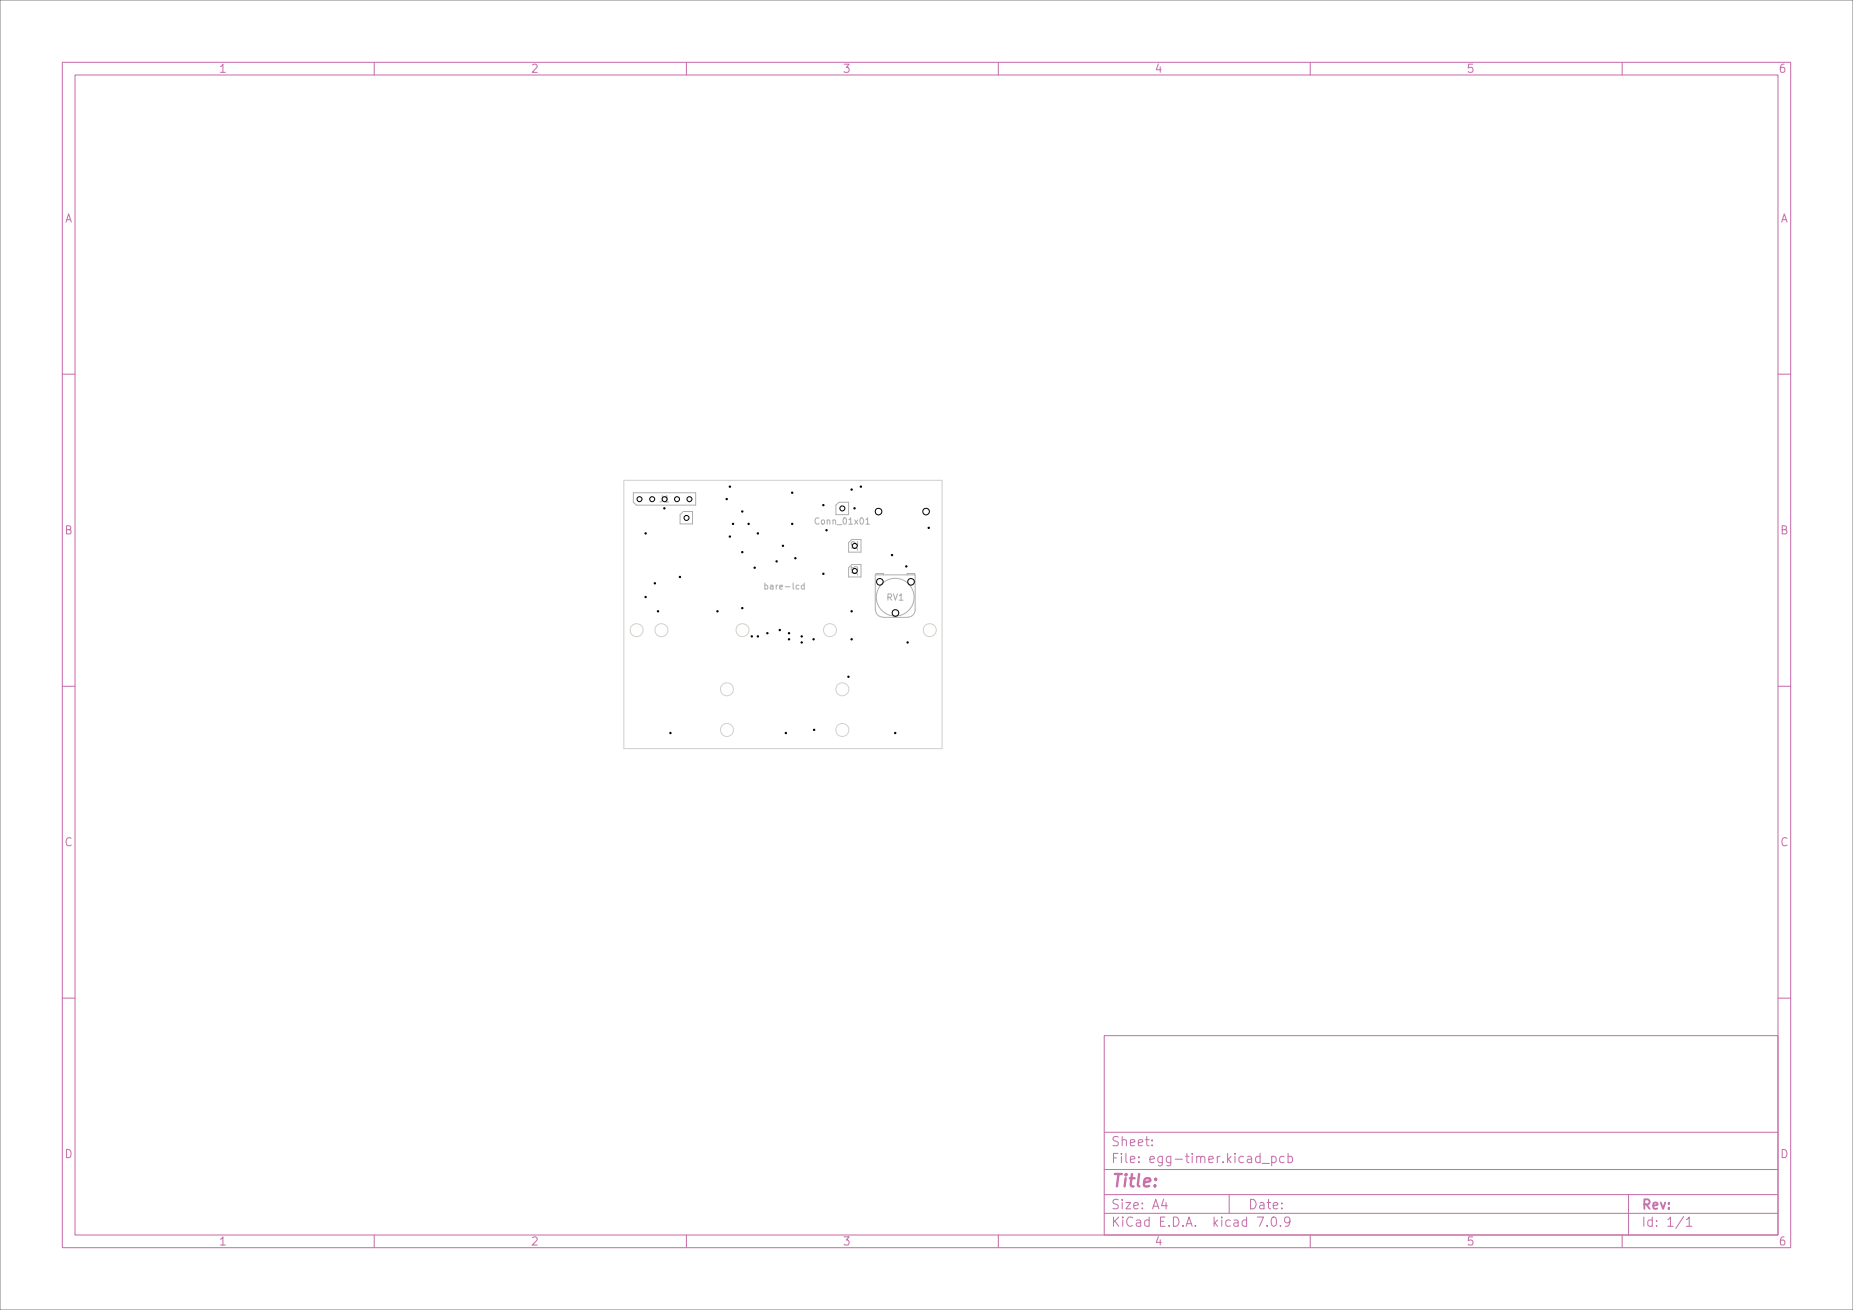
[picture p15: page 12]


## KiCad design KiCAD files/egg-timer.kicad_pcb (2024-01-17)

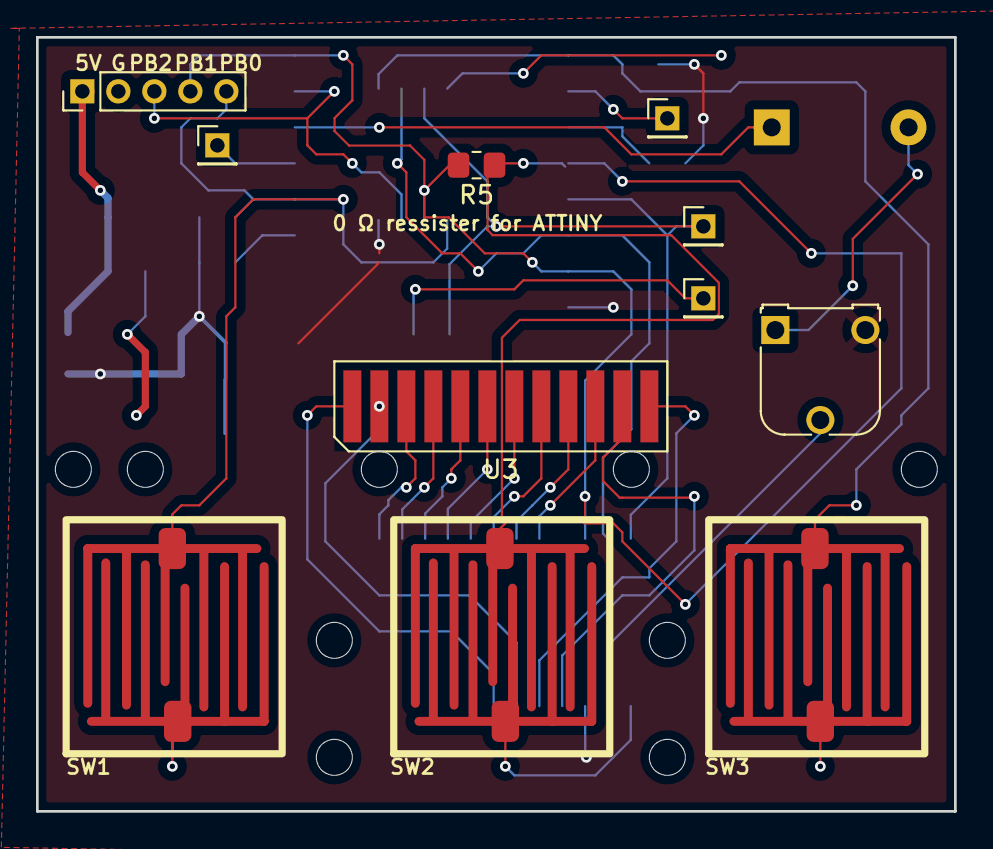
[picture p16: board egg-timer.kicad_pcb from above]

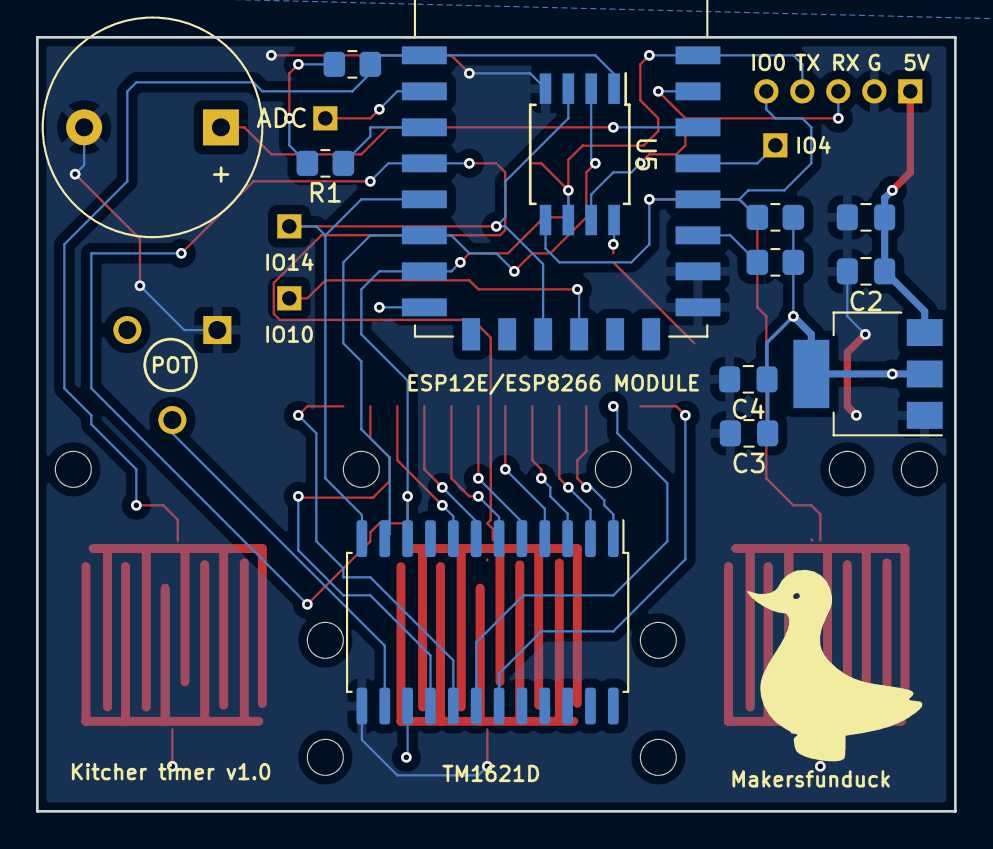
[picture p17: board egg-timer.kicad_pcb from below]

Board: 2 copper layers, 51.0 x 43.0 mm, 24 parts (13 on the bottom side), 29 nets.

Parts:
BZ1: Buzzer; Buzzer_12x9.5RM7.6
C1, C3: 10uF; C_0805_2012Metric_Pad1.18x1.45mm_HandSolder
C2, C4: 100nF; C_0805_2012Metric_Pad1.18x1.45mm_HandSolder
J1: Conn_01x05; PinHeader_1x05_P2.00mm_Vertical
J2, J3, J4, J5: Conn_01x01; PinHeader_1x01_P2.00mm_Vertical
R1, R2, R4: 1k; R_0805_2012Metric_Pad1.20x1.40mm_HandSolder
R3: 1K; R_0805_2012Metric_Pad1.20x1.40mm_HandSolder
R5: 0Ω; R_0805_2012Metric_Pad1.20x1.40mm_HandSolder
RV1: R_Potentiometer; Potentiometer_Runtron_RM-065_Vertical
SW1, SW2, SW3: SW_Push; contact pad
U1: ESP-12E
U2: TM1621D; SOIC-24W_7.5x15.4mm_P1.27mm
U3: bare-lcd; bare-lcd-footprint12
U4: AMS1117-3.3; SOT-223-3_TabPin2
U5: ATtiny13A-S; SOIC-8W_5.3x5.3mm_P1.27mm

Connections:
5V: C1.1, C2.1, J1.1, U4.3 (VI)
+3.3V: C3.1, C4.1, R1.2, R2.1, R3.1, R4.1, RV1.3, U1.8 (VCC), U2.15 (VDD), U4.2 (VO), U5.8 (VCC)
ADC: J5.1, U1.2 (ADC)
COM0: U2.16 (COM0), U3.11
COM1: U2.17 (COM1), U3.12
COM2: U2.18 (COM2), U3.2
COM3: U2.19 (COM3), U3.1
GND: BZ1.2 (+), C1.2, C2.2, C3.2, C4.2, J1.2, RV1.1, SW1.1, SW2.1, SW3.1, U1.15 (GND), U1.16 (GPIO15), U2.13 (VSS), U4.1 (GND), U5.4 (GND)
IO0: J1.5, R3.2, SW1.2, U1.18 (GPIO0), U5.5 (PB0)
IO4: J4.1, U1.19 (GPIO4)
IO5: BZ1.1 (-), U1.20 (GPIO5)
IO10: J3.1, U1.12 (GPIO10)
IO12: U1.6 (GPIO12), U2.11 (WR#), U5.2 (PB3)
IO13: J1.4, R5.2, U1.7 (GPIO13), U1.22 (GPIO1/TXD), U2.10 (CS#), U5.6 (PB1)
IO14: J2.1, U1.5 (GPIO14), U1.11 (GPIO9), U2.12 (DATA#), U5.3 (PB4)
IO16: R5.1, SW2.2, U1.4 (GPIO16)
unnamed: R1.1, U1.3 (EN)
unnamed: R4.2, U1.17 (GPIO2)
unnamed: RV1.2, U2.14 (VLCD)
PB2: J1.3, U1.21 (GPIO3/RXD), U5.7 (PB2)
RST: R2.2, SW3.2, U1.1 (~RST), U5.1 (~RESET/PB5)
SEG1: U2.1 (SEG17), U3.3
SEG2: U2.2 (SEG16), U3.4
SEG3: U2.3 (SEG15), U3.5
SEG4: U2.4 (SEG14), U3.6
SEG5: U2.5 (SEG13), U3.7
SEG6: U2.6 (SEG12), U3.8
SEG7: U2.7 (SEG11), U3.9
SEG8: U2.8 (SEG10), U3.10

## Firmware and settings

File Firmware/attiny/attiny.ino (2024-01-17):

#include "TM1621D.h"

#define PIN_TM1621D_BL     PB0
#define PIN_TM1621D_CS     PB1
#define PIN_TM1621D_RW     PB3
#define PIN_TM1621D_DATA   PB4












struct DisplayConfig {
    uint8_t m4b;   // MSB 4 bits
    uint8_t l4b;   // LSB 4 bits
    bool bitHL;    // High bits or Low bits
};

uint8_t displayMemory[18];  // Display Segments Memory

DisplayConfig digMap[18] = { //High, Low
    {11,10,  true}, { 9, 8,  true}, { 7, 6,  true},  { 5, 4,  true}, { 3, 2,  true}, { 1, 0,  true}, // Row 1
    {11,10, false}, { 9, 8, false}, { 7, 6, false},  { 5, 4, false}, { 3, 2, false}, { 1, 0, false}, // Row 2
    {12,13,  true}, {14,15,  true}, {16,17,  true},  {12,13, false}, {14,15, false}, {16,17, false}  // Row 3
};

uint8_t segments[] = {
    //GBDCFAME
    0b01111101,  // 0
    0b01010000,  // 1
    0b11100101,  // 2
    0b11110100,  // 3
    0b11011000,  // 4
    0b10111100,  // 5
    0b10111101,  // 6
    0b01010100,  // 7
    0b11111101,  // 8
    0b11111100,  // 9
    0b00000000   // [Empty]
};

TM1621D ht(PIN_TM1621D_CS, PIN_TM1621D_RW, PIN_TM1621D_DATA);

void writeDigit(uint8_t d, uint8_t num){
    DisplayConfig df = digMap[d];
    writeSegments(d, segments[num]);
}

void writeSegments(uint8_t d, uint8_t segData){
    DisplayConfig df = digMap[d];
    uint8_t high4Bit = segData >> 4;
    uint8_t low4Bit  = segData & 0b1111;
    
    if( df.bitHL ){
        high4Bit = high4Bit << 4;
        low4Bit  = low4Bit << 4;
        displayMemory[df.m4b] = displayMemory[df.m4b] & 0b00001111;
        displayMemory[df.l4b] = displayMemory[df.l4b] & 0b00001111;
        displayMemory[df.m4b] = displayMemory[df.m4b] | high4Bit;
        displayMemory[df.l4b] = displayMemory[df.l4b] | low4Bit;
    }else{
        displayMemory[df.m4b] = displayMemory[df.m4b] & 0b11110000;
        displayMemory[df.l4b] = displayMemory[df.l4b] & 0b11110000;
        displayMemory[df.m4b] = displayMemory[df.m4b] | high4Bit;
        displayMemory[df.l4b] = displayMemory[df.l4b] | low4Bit;
    }
    
    ht.write(df.m4b, displayMemory[df.m4b]);
    ht.write(df.l4b, displayMemory[df.l4b]);
}


void setup() {
  
    uint8_t i;
    pinMode(PIN_TM1621D_BL, OUTPUT);
    digitalWrite(PIN_TM1621D_BL, LOW);

    ht.begin();
    
    ht.sendCommand(TM1621D::RC256K);
    ht.sendCommand(TM1621D::BIAS_THIRD_4_COM);
    ht.sendCommand(TM1621D::SYS_EN);
    ht.sendCommand(TM1621D::LCD_ON);

    //Clear display
    for(i=0; i<18; i++){
        displayMemory[i] = 0;
        ht.write(i,0);
    }
  

    digitalWrite(PIN_TM1621D_BL, HIGH); //Turn on backlight LED
    

    digitalWrite(PIN_TM1621D_BL, LOW); //Turn off backlight LED
    
    // write all segments (even dp)
    for(i=0; i<18; i++){
        ht.write(i, 0xFF);
       
        delay( 2000 );
    }

    
    //Clear display
    for(i=0; i<18; i++){
        displayMemory[i] = 0;
        ht.write(i,0);
    }
}

void loop() {

      for(int i=5; i<9; i++){
      /* 
      ht.write(i, 0b00000001); //e
        delay( 1000 );
        ht.write(i, 0b00000010); //ms
        delay( 1000 );

        ht.write(i, 0b00000100); //a
        delay( 1000 );
        ht.write(i, 0b00001000); //f
        delay( 1000 );
        ht.write(i, 0b00010000); //c
        delay( 1000 );

        ht.write(i, 0b00100000); //d
        delay( 1000 );
        ht.write(i, 0b10000000); // g
        delay( 1000 );
        ht.write(i, 0b01000000); //b
        delay( 1000 );
        */
    for(int J=0; J<10; J++){
       ht.write(i, segments[J]); //b
        delay( 1000 );
        }
    }
}



  

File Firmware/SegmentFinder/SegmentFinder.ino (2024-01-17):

/*
LCD segment finder


*/
#define freq 5
// the setup function runs once when you press reset or power the board
void setup() {
  // initialize digital pin LED_BUILTIN as an output.
  pinMode(8, OUTPUT);
  pinMode(9, OUTPUT);
}

// the loop function runs over and over again forever
void loop() {
  digitalWrite(8, HIGH);  // turn the LED on (HIGH is the voltage level)
  digitalWrite(9, LOW);   // turn the LED off by making the voltage LOW
  delay(freq);                      // wait for a second
  digitalWrite(8, LOW);   // turn the LED off by making the voltage LOW
  digitalWrite(9, HIGH);  // turn the LED on (HIGH is the voltage level)
  delay(freq);                      // wait for a second
}
